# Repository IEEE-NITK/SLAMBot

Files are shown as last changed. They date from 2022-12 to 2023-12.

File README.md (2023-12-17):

# SLAMBot

## Achievements

- <span style="font-size: 1.2em;">**Winner of the IEEE R10 Undergraduate Project Video Competition 2023**</span>
  - <span style="font-size: 1.2em;">Category: AI and Robotics</span>
  - <span style="font-size: 1.2em;">[View Announcement](https://sac.ieeer10.org/ug-student-project-video-contest/)</span>
- <span style="font-size: 1.2em;">**Featured on IEEE R10 SAC LinkedIn page**</span>
  - <span style="font-size: 1.2em;">[Check out the post](https://www.linkedin.com/feed/update/urn:li:activity:7112096967022845952/)</span>
- <span style="font-size: 1.2em;">**IEEE R10 Undergraduate Student Project Video Contest Submission**</span>
  - <span style="font-size: 1.2em;">[Watch the Video](https://www.youtube.com/watch?v=xg2uQ87B_d8)</span>







<br>
<details>
  <summary>Table of Contents</summary>
    <ol>
        <li>
            <a href="#introduction">Introduction</a>
            <ul>
                <li><a href="#technologies-used">Technologies Used</a></li>
            </ul>
        </li>
        <li>
            <a href="#literature-survey">Literature Survey</a>
            <ul>
                <li><a href="#robot-operating-system-ros">Robot Operating System (ROS)</a></li>
                <li><a href="#basic-terminologies-in-ros">Basic Terminologies in ROS</a></li>
                <li><a href="#turtlebot">Turtlebot</a></li>
                <li><a href="#lidar">LIDAR</a></li>
                <li><a href="#raspberry-pi">Raspberry Pi</a></li>
                <li><a href="#arduino-mega">Arduino Mega</a></li>
            </ul>
        </li>
        <li>
            <a href="#getting-started">Getting Started</a>
            <ul>
            <li><a href="#prerequisites">Prerequisites</a></li>
            <li><a href="#installation">Installation</a></li>
            </ul>
        </li>
        <li>
            <a href="#user-guide">User Guide</a>
                <ul>
                    <li><a href="#launching-gazebo-simulation">Launching Gazebo Simulation</a></li>
                    <li><a href="#slam-creating-a-map">SLAM: Creating a Map</a></li>
                    <li><a href="#saving-the-map">Saving the Map</a></li>
                    <li><a href="#slam-autonomous-navigation">SLAM: Autonomous Navigation</a></li>
                </ul>    
        </li>
        <li>
            <a href="#the-robot">The Robot</a> 
        </li>
        <li>
            <a href="#references">References</a> 
        </li>
        <li>
            <a href="#project-mentors">Project Mentors</a></li>
        </li>
        <li>
            <a href="#project-members">Project Members</a></li>
        </li> 
        <li>
            <a href="#license">License</a></li>
        </li>    
    </ol>
</details>

<hr>

## Introduction

<b>SLAM</b> (<b>S</b>imultaneous <b>L</b>ocalization <b>A</b>nd <b>M</b>apping) is an essential technology used in robotics that helps robots to estimate their position and orientation on a map while creating a map of the environment to carry out autonomous activities. 

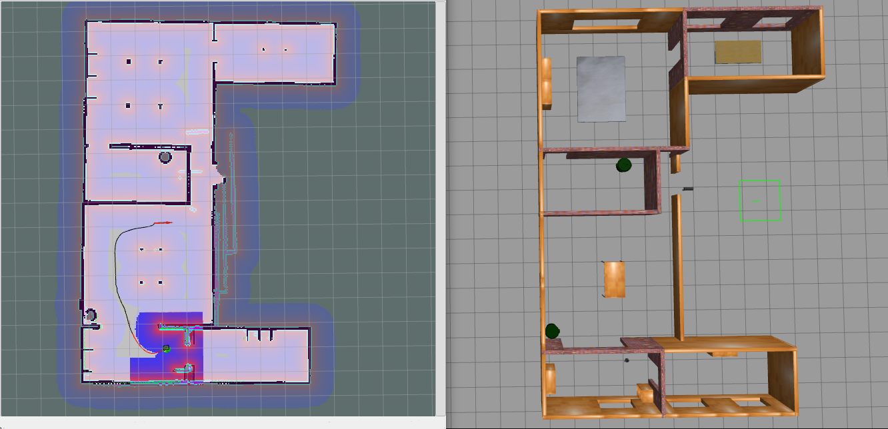
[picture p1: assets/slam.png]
SLAM

*Turtlebot using SLAM to navigate across a map*

This project aims to put together a mobile robot similar to a TurtleBot. A TurtleBot is a low-cost personal robot kit with open-source software.

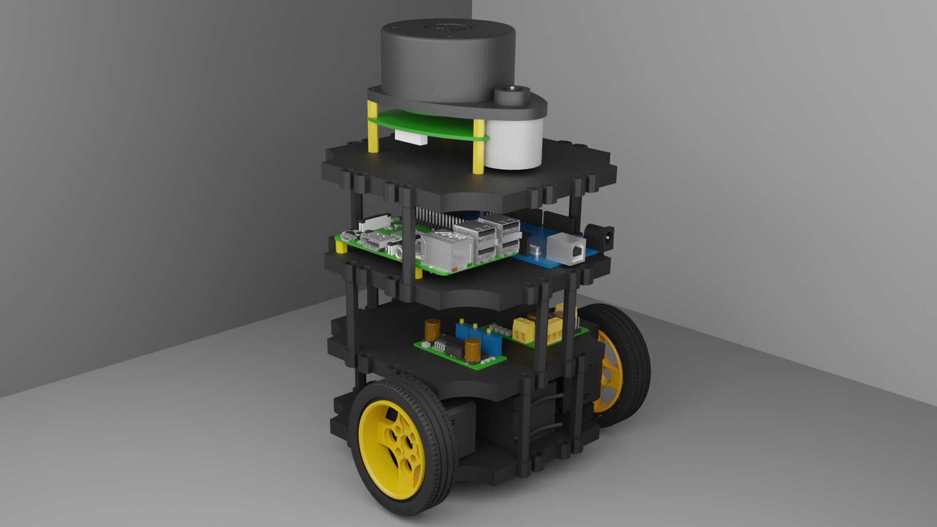
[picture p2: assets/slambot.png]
SlamBot

*SLAMBot Rendition*

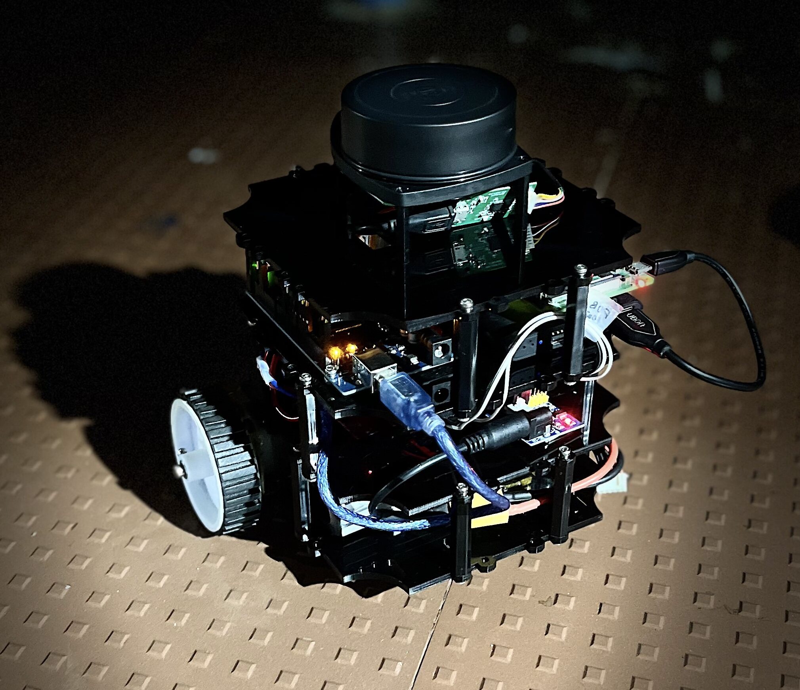
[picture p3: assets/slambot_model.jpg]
SlamBot Model

*Working model of SLAMBot*

### Technologies Used
Tech_Used (https://skills.thijs.gg)

## Literature Survey

### Robot Operating System (ROS)

ROS is an open-source, meta-operating system to operate robots. ROS provides the services of an operating system, such as hardware abstraction, low-level device control, implementation of commonly-used functionality, message-passing between processes, and package management. ROS provides tools and libraries for obtaining, building, writing, and running code across multiple computers. ROS currently only runs on Unix-based platforms. Software for ROS is primarily tested on Ubuntu and Mac OS X systems, though the ROS community has been contributing support for Fedora, Gentoo, Arch Linux, and other Linux platforms.

### Basic Terminologies in ROS:

* Nodes: A node is an executable that uses ROS to communicate with other nodes. A ROS Node can be a Publisher or a Subscriber. A Publisher puts the messages of a standard message type to a particular topic. The Subscriber, on the other hand, subscribes to the topic and receives the messages that are published to the topic.
* Messages: ROS data type used upon subscribing or publishing to a topic.
* Topics: Nodes can publish messages to a topic as well as subscribe to a topic to receive messages.
* Master: Name service for ROS (i.e. helps nodes find each other)
* rosout: ROS equivalent of stdout/stderr
* roscore: Master + rosout + parameter server (parameter server will be introduced later)

Client libraries needed for this project: 
* rospy: python client library 
* roscpp: c++ client library

### Turtlebot:

TurtleBot3 is a small, affordable, programmable, ROS-based mobile robot for education, research, hobby, and product prototyping. The TurtleBot’s core technology is SLAM, Navigation, and Manipulation, making it suitable for home service robots.
<p>
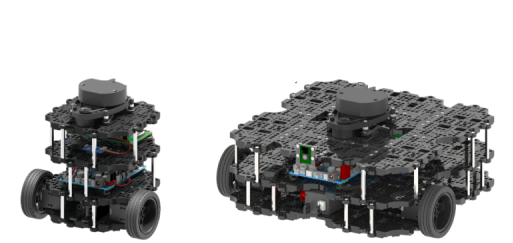
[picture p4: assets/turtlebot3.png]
Turtlebot
     
    <br>
    <em>Turtlebot3 Models - Burger and Waffle</em>
</p>

### LIDAR:

A <b>LIDAR</b> (<b>LI</b>ght <b>D</b>etection <b>A</b>nd <b>R</b>anging) is a sensor that uses light in the form of a pulsed laser to calculate the relative distances of various objects. This 3D scanning system calculates how long it takes for beams of light to hit an object or surface and reflect back to the laser scanner using the velocity of light. The observed LIDAR data is then used to generate precise, three dimensional information about the environment of the robot and navigate smoothly while avoiding the obstacles.

### Raspberry Pi:

The Raspberry Pi is an affordable single-board computer that can run Linux operating system such as Raspbian and Ubuntu. It is extensively used to develop programming skills or build hardware projects. It is a fast and versatile microprocessing board along with a set of GPIO (General Purpose Input/Output) pins, allowing one to control electronic components for physical computing. This project uses a Raspberry Pi 3B.

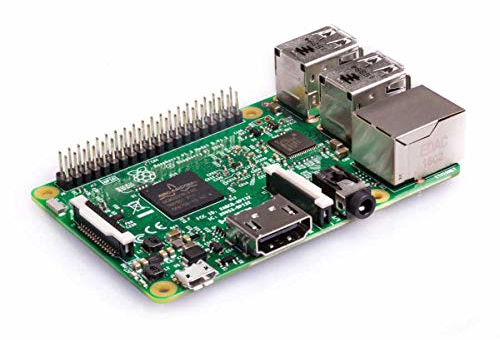
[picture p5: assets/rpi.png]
Raspi 3B
 
<br>
*Raspberry Pi Model B*

### Arduino Mega:

Arduino is an open-source electronics platform based on easy-to-use hardware and software intended for applications in interactive projects. Arduino Mega is a microcontroller development board based on the ATmega2560 microcontroller IC. It can be interfaced with various hardware components such as sensors and actuators. Arduino can be programmed using Arduino C which is a language based on C++.

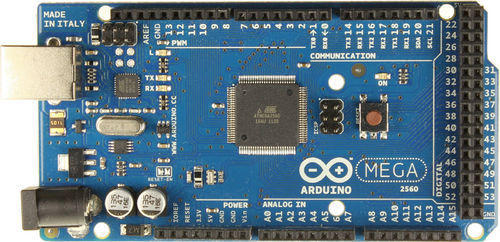
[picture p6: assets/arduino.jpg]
Arduino

<br>
*Arduino Mega*

## Getting Started

### Prerequisites

* Ubuntu 20.04
* ROS Noetic 

> For installing ROS refer to [ROS Wiki](http://wiki.ros.org/noetic/Installation)

### Installation

Create a catkin workspace

```bash
mkdir ros_ws
cd ros_ws
mkdir src
catkin build
```
To automatically source this workspace every time a new shell is launched, run these commands

```bash
echo "source ~/ros_ws/devel/setup.bash" >> ~/.bashrc
source ~/.bashrc
```

Clone the repository in the `src` folder in the catkin workspace.

```bash
cd ~/ros_ws/src
git clone https://github.com/IEEE-NITK/SLAMBot.git
```

Navigate back to the workspace folder and build the packages.

```bash
cd ~/ros_ws
catkin build
```

## User Guide

### Launching Gazebo Simulation

To launch the gazebo simulation use the command

```bash
roslaunch slambot_simulation slambot_simulation.launch
```

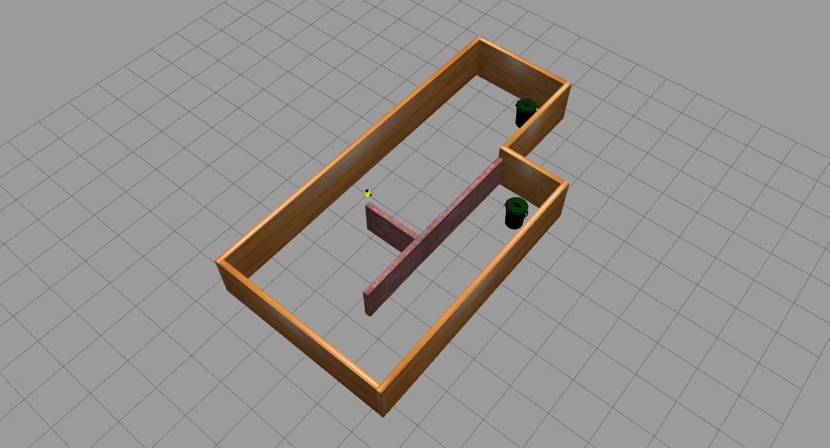
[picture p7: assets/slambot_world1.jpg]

<br>
*Slambot Simulation World*

To move the robot around, we will use teleop_twist_keyboard which is a package for moving the robot using the keyboard: 

```bash
rosrun teleop_twist_keyboard teleop_twist_keyboard.py 
```
### SLAM: Creating a Map

Before we can autonomously drive around any world, we need to provide the robot with a map which will be used to localize (position) the robot relative to obstacles or features defined in the map. We will create a new map of the default world by doing the following:

1. Launch the world in Gazebo
2. Launch the mapping script
3. Drive around and collect data from the robot's sensors until we have a (nearly) complete and accurate map.

After launching the gazebo simulation and teleoperation, use the following command to create a map using gmapping algorithm:

```bash
roslaunch slambot_simulation slambot_slam.launch
```

Now, with the terminal running the teleop_twist_keyboard selected, drive the robot around using the ```I```, ```J```, ```L```, ```,``` and ```K``` keys.

https://user-images.githubusercontent.com/97270737/211186864-b15c18e0-27f7-4a30-bb05-f40773bdc2ec.mp4

Once your map has all of the features defined (black for walls or obstacles, white for no obstacles, and gray/transparent for unknown regions), we need to save the map.

### Saving the Map

In a new terminal, run:

```bash
rosrun map_server map_saver -f ~/map
```

This will create two files:
* map.pgm - the image containing the white, gray, and black regions.
* map.yaml - the configuration data for the map.pgm image.

### SLAM: Autonomous Navigation

Now that the map of the world is prepared, we can drive the robot autonomously inside the world. To do this, we will:

1. Launch the gazebo simulation
2. Launch the naviation script
3. Set an initial pose estimate to align the map relative to the current sensor data (i.e. perform an initial localization)
4. Set target (goal) positions and orientations for the robot to drive to
5. Have the robot navigate to the goal autonomously

To launch the gazebo simuation, in a terminal run:

```bash
roslaunch slambot_simulation slambot_simulation.launch
```

Then in a new terminal, run

```bash
roslaunch slambot_simulation slambot_navigation.launch 
```
This will open an RViz window with the map and the robot with the current sensor values displayed.

In RViz

1. Select 2D Pose Estimate. Click and drag an arrow that estimates where the robot is currently positioned relative to the map that we created.
2. This will allign the robot to the map according to the current sensor feed.
3. Next, select 2D Nav Goal.
4. Click and drag an arrow that represents the position and orientation of where the robot needs to drive to. In order for a path to be calculated, this arrow must be inside a white or gray region, signifying that there is no known obstacle at the goal location.
5. The robot will compute a local path (a yellow arc) and a global path (the blue or red spline), and will autonomously drive to the target position.

https://user-images.githubusercontent.com/97270737/223050171-1a2402c0-27b5-4226-9031-b165af7b2f46.mp4

## The Robot

The robot model used in this project is a simple differential drive comprising of 2 wheels mounted on their motor along with a roller castor for additional base support.

The robot consists of 4 layers:

* Bottom-most layer: The propulsion group comprising of battery and motors.
* Second layer: It consists of the power distribution board along with motor drivers.
* Third layer: This layer has an Raspberry Pi, which is a single board computer, along with an Arduino Mega microcontroller.
* Top-most layer: It comprises of the LIDAR

The above mentioned plates are 3D printed parts which are further assembled with the electronic hardware using screws and supports to ensure stability of the structure.

The design of the bot is created on Fusion 360, a commercial CAD and CAM software. It is then directly exported as a URDF (Unified Robotic Description Format) file, accompanied by a .stl file of the model alongside a .launch and .yaml file to simulate it on Gazebo. The URDF is an XML file format for specifying the geometry and organization of robots in ROS and can be generated using URDF_Exporter. 

The robot is simulated in Gazebo, a powerful, open-source 3D robotics simulator with the ability to accurately and efficiently generate synthetic sensor data and offers realistic environments with high fidelity sensors streams to construct and interact with simulations. Within Gazebo, a physics engine is used to define realistic elements of an environment such as illumination, gravity and inertia.

## References

1. [ROS Wiki](http://wiki.ros.org/ROS/Tutorials)
2. [Turtlebot](https://www.turtlebot.com/about/)
3. [SLAM and Turtlebot](https://emanual.robotis.com/docs/en/platform/turtlebot3/slam/)

## Project Guide:
[Shobuj Paul](https://github.com/Shobuj-Paul)

## Project Mentors:

1. [Shivani Chanda](https://github.com/Shivani-Chanda)
2. [Spandan Patkar](https://github.com/SpandanPatkar)
3. [Sunaina Sunil](https://github.com/SunainaSunil)

## Project Members:

1. [Joel Jojo Painuthara](https://github.com/JoelJojoP)
2. [Pooja M](https://github.com/pooja-murugiah)
3. [Sakshi Bothra](https://github.com/Sakshi-1606)

## License:

This repository is licensed under the [BSD-3-Clause License](https://github.com/IEEE-NITK/SLAMBot/blob/main/LICENSE)

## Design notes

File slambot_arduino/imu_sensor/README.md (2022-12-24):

# Interfacing a MPU 9255 Sensor with Arduino Nano/Uno and ROS

Follow [this](https://github.com/Bill2462/MPU9255-Arduino-Library) GitHub repository to connect a MPU9255 IMU with a Arduino Board (Nano/Uno/Mega). Tested with Uno and Nano.

Follow the pin connections as given in the README. Import the library and use the given paramters as in the sample code.

Interface with ROS by declaring Publishers of message type **geometry_msgs/Vector3** to publish the IMU measurements to ROS after running `serial_node.py` (refer to main README).

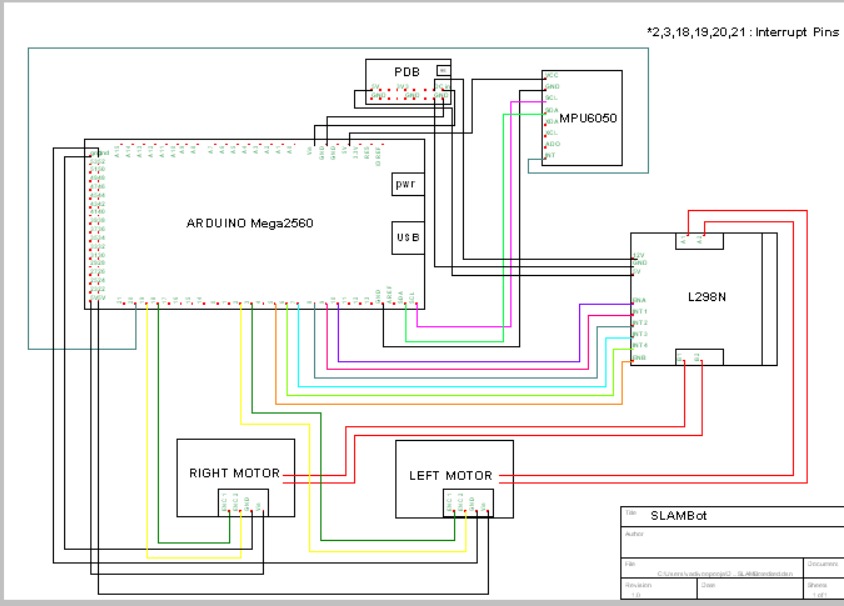
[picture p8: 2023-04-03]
pinout.jpeg

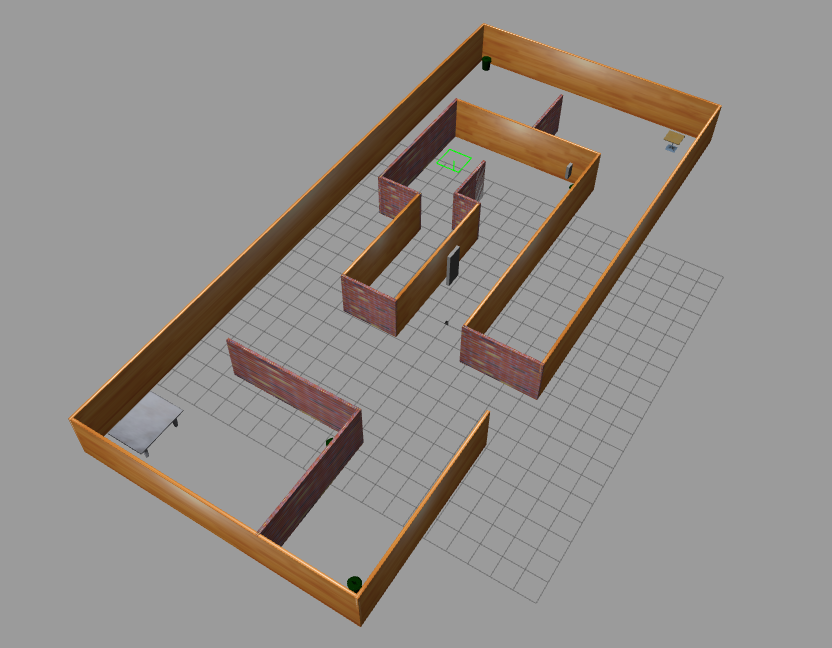
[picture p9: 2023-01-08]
assets/slambot_world.png

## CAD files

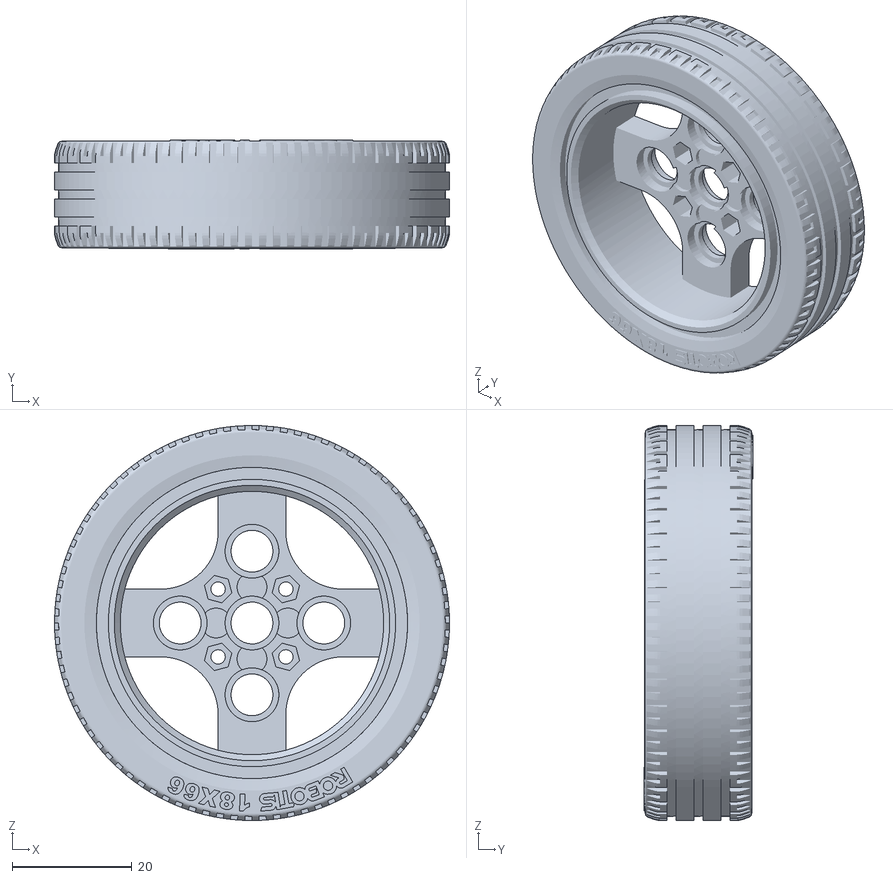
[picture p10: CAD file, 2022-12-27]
slambot_description/meshes/wheel_right_1.stl
66.0 x 18.2 x 66.0

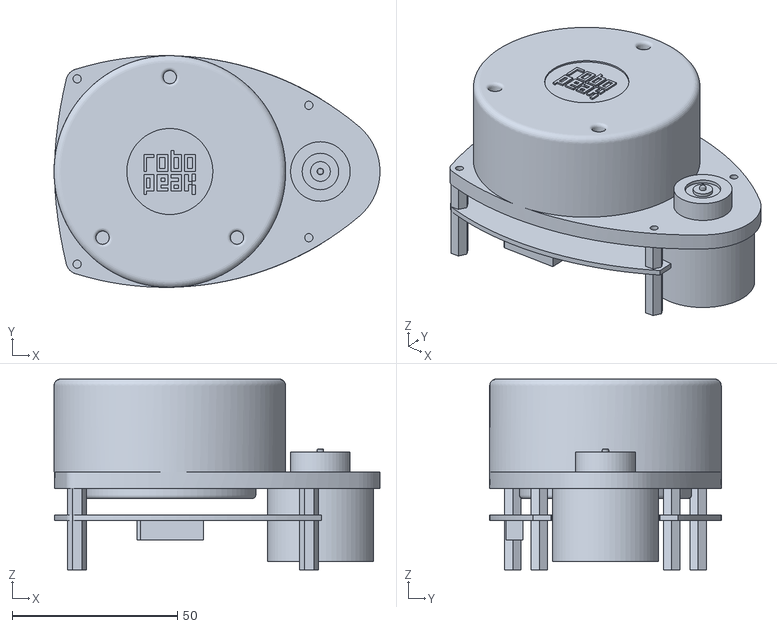
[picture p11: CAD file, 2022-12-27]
slambot_description/meshes/lidar_1.stl
98.5 x 70.0 x 57.7

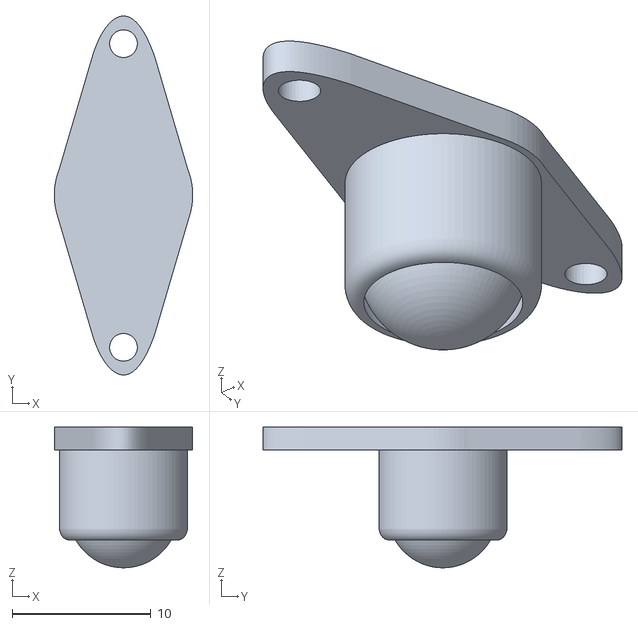
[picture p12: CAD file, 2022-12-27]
slambot_description/meshes/wheel_caster_1.stl
10.00 x 25.9 x 10.2

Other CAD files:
slambot_description/meshes/wheel_left_1.stl

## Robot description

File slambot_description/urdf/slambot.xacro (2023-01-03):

<?xml version="1.0" ?>
<robot name="slambot" xmlns:xacro="http://www.ros.org/wiki/xacro">

<xacro:include filename="$(find slambot_description)/urdf/materials.xacro" />
<xacro:include filename="$(find slambot_description)/urdf/slambot.trans" />
<xacro:include filename="$(find slambot_description)/gazebo/slambot_materials.gazebo" />
<xacro:include filename="$(find slambot_description)/gazebo/slambot_physics.gazebo" />
<xacro:include filename="$(find slambot_description)/gazebo/slambot_plugins.gazebo" />

<link name="base_footprint"/>
<link name="base_link">
  <inertial>
    <origin xyz="0.0028609830961275496 -0.00028636548319819235 0.07416570528182598" rpy="0 0 0"/>
    <mass value="5.29438449819002"/>
    <inertia ixx="0.018437" iyy="0.018264" izz="0.012718" ixy="4e-05" iyz="5.8e-05" ixz="0.000436"/>
  </inertial>
  <visual>
    <origin xyz="0 0 0" rpy="0 0 0"/>
    <geometry>
      <mesh filename="package://slambot_description/meshes/base_link.stl" scale="0.001 0.001 0.001"/>
    </geometry>
    <material name="opaque898684"/>
  </visual>
  <collision>
    <origin xyz="0 0 0" rpy="0 0 0"/>
    <geometry>
      <mesh filename="package://slambot_description/meshes/base_link.stl" scale="0.001 0.001 0.001"/>
    </geometry>
  </collision>
</link>

<link name="wheel_right_1">
  <inertial>
    <origin xyz="1.4796994004112607e-06 -0.00781748340988625 8.287650255650592e-08" rpy="0 0 0"/>
    <mass value="0.2346100571054497"/>
    <inertia ixx="9e-05" iyy="0.000167" izz="9e-05" ixy="0.0" iyz="-0.0" ixz="-0.0"/>
  </inertial>
  <visual>
    <origin xyz="-0.03275 0.0722 -0.033" rpy="0 0 0"/>
    <geometry>
      <mesh filename="package://slambot_description/meshes/wheel_right_1.stl" scale="0.001 0.001 0.001"/>
    </geometry>
    <material name="steel_satin"/>
  </visual>
  <collision>
    <origin xyz="-0.03275 0.0722 -0.033" rpy="0 0 0"/>
    <geometry>
      <mesh filename="package://slambot_description/meshes/wheel_right_1.stl" scale="0.001 0.001 0.001"/>
    </geometry>
  </collision>
</link>

<link name="wheel_left_1">
  <inertial>
    <origin xyz="1.4796994003002384e-06 0.007817483409885487 -8.287650261201707e-08" rpy="0 0 0"/>
    <mass value="0.2346100571054497"/>
    <inertia ixx="9e-05" iyy="0.000167" izz="9e-05" ixy="-0.0" iyz="-0.0" ixz="0.0"/>
  </inertial>
  <visual>
    <origin xyz="-0.03275 -0.0722 -0.0333" rpy="0 0 0"/>
    <geometry>
      <mesh filename="package://slambot_description/meshes/wheel_left_1.stl" scale="0.001 0.001 0.001"/>
    </geometry>
    <material name="steel_satin"/>
  </visual>
  <collision>
    <origin xyz="-0.03275 -0.0722 -0.0333" rpy="0 0 0"/>
    <geometry>
      <mesh filename="package://slambot_description/meshes/wheel_left_1.stl" scale="0.001 0.001 0.001"/>
    </geometry>
  </collision>
</link>

<link name="wheel_caster_1">
  <inertial>
    <origin xyz="-0.045000594596254544 1.735967801928781e-05 -0.00355326377799727" rpy="0 0 0"/>
    <mass value="0.0054901244015141525"/>
    <inertia ixx="0.0" iyy="0.0" izz="0.0" ixy="-0.0" iyz="0.0" ixz="0.0"/>
  </inertial>
  <visual>
    <origin xyz="-0.0 0.0 -0.01105" rpy="0 0 0"/>
    <geometry>
      <mesh filename="package://slambot_description/meshes/wheel_caster_1.stl" scale="0.001 0.001 0.001"/>
    </geometry>
    <material name="steel_satin"/>
  </visual>
  <collision>
    <origin xyz="-0.0 0.0 -0.01105" rpy="0 0 0"/>
    <geometry>
      <mesh filename="package://slambot_description/meshes/wheel_caster_1.stl" scale="0.001 0.001 0.001"/>
    </geometry>
  </collision>
</link>

<link name="lidar_1">
  <inertial>
    <origin xyz="-0.008711210990347865 -9.19261111398959e-05 0.03526812773284044" rpy="0 0 0"/>
    <mass value="1.3392997077576572"/>
    <inertia ixx="0.000619" iyy="0.000967" izz="0.001105" ixy="-1e-06" iyz="-3e-06" ixz="0.000159"/>
  </inertial>
  <visual>
    <origin xyz="-0.0 -0.0 -0.15105" rpy="0 0 0"/>
    <geometry>
      <mesh filename="package://slambot_description/meshes/lidar_1.stl" scale="0.001 0.001 0.001"/>
    </geometry>
    <material name="coating_black_oxide"/>
  </visual>
  <collision>
    <origin xyz="-0.0 -0.0 -0.15105" rpy="0 0 0"/>
    <geometry>
      <mesh filename="package://slambot_description/meshes/lidar_1.stl" scale="0.001 0.001 0.001"/>
    </geometry>
  </collision>
</link>

<joint name="base_joint" type="fixed">
  <parent link="base_footprint"/>
  <child link="base_link"/>
</joint>

<joint name="motor_right" type="continuous">
  <origin xyz="0.03275 -0.0722 0.033" rpy="0 0 0"/>
  <parent link="base_link"/>
  <child link="wheel_right_1"/>
  <axis xyz="0.0 1.0 0.0"/>
</joint>

<joint name="motor_left" type="continuous">
  <origin xyz="0.03275 0.0722 0.0333" rpy="0 0 0"/>
  <parent link="base_link"/>
  <child link="wheel_left_1"/>
  <axis xyz="-0.0 1.0 -0.0"/>
</joint>

<joint name="caster_joint" type="fixed">
  <origin xyz="0.0 0.0 0.01105" rpy="0 0 0"/>
  <parent link="base_link"/>
  <child link="wheel_caster_1"/>
</joint>

<joint name="lidar_joint" type="fixed">
  <origin xyz="0.0 0.0 0.15105" rpy="0 0 0"/>
  <parent link="base_link"/>
  <child link="lidar_1"/>
</joint>

</robot>

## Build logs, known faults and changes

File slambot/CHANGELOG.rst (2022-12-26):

^^^^^^^^^^^^^^^^^^^^^^^^^^^^^^^^
Changelog for package slambot
^^^^^^^^^^^^^^^^^^^^^^^^^^^^^^^^

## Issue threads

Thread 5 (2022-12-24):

Arduino code and hardware interface to ROS

Shobuj-Paul, 2022-12-24:
Embedded code must be written to interface with Arduino Mega and the other sensors, such as encoders and IMU. This embedded code is written with the rosserial_arduino package library for easy serial interface with the companion computer.
All _.ino_ codes are maintained in [this](https://github.com/IEEE-NITK/SLAMBot/tree/main/slambot_arduino) folder and template code for rosserial is added [here](https://github.com/IEEE-NITK/SLAMBot/blob/main/slambot_arduino/differential_drive/differential_drive.ino).

Closed 2022-12-27.

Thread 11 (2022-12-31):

Differential Drive Plugin

Shobuj-Paul, 2022-12-31:
## Use case

To control the robot in Gazebo using keyboard bindings, we need to set up `/cmd_vel` topic which connects to the wheel controllers using a differential drive setup.

## Proposal

Use the [differential drive plugin](https://classic.gazebosim.org/tutorials?tut=ros_gzplugins#DifferentialDrive) as given in Gazebo documentation and edit the given parameters in the _slambot_plugins.gazebo_ file given [here](https://github.com/IEEE-NITK/SLAMBot/blob/differential_drive_plugin/slambot_description/gazebo/slambot_plugins.gazebo). Get the robot's physical parameters from the CAD model in Fusion360.

Shivani-Chanda, 2023-01-03:
differential drive plugin updated with the correct physical parameters.

Closed 2023-01-03.

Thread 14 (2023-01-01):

Embedded code for rosserial communication

Shobuj-Paul, 2023-01-01:
## Description

The Arduino side rosserial codes do not connect to any hardware actions yet. Functions for calculating odometry, transform, etc. need to be completed and stored in their respective message types for proper publisher-subscriber relations.

## Steps to Reproduce

Open the [_differential_drive.ino_](https://github.com/IEEE-NITK/SLAMBot/blob/rosserial/slambot_arduino/differential_drive/differential_drive.ino) code in Arduino IDE. Upload it to your Arduino Mega board after setting the port and board parameters.
Run the rosserial node after running `roscore`:
```bash
rosrun rosserial_arduino serial_node.py
```
Running `rostopic list` gives you a bunch of topics on your Linux PC, but the contents of these topics are blank (check `rostopic echo`). Do the necessary calculations and complete the Arduino functions. Complete the `void loop()` part of the code.

### Expected Results

Sensor readings from Encoders, IMU, etc., should be published accurately on the computer. Motors should correctly respond to `/cmd_vel` command given on the computer.

### Actual results

Blank topics, no response from `/cmd_vel`.

<!-- ## Screenshots (optional)

      Consider also attaching screenshots and/or videos to better
      illustrate the issue.

      You can upload them directly on GitHub by dragging and dropping into this issue.
      Beware that video file size is limited to 10MB.
-->

## Configuration

### ROS Configuration

Which ROS Version are you using?

- [x] Noetic
- [ ] Melodic
- [ ] Foxy
- [ ] Humble
- [ ] Rolling

### Operating System

Which OS are you using?

- [ ] Windows
- [ ] MacOS
- [x] Ubuntu Linux (Mention Version) 20.04
- [ ] Other Linux (Mention Below)

Shobuj-Paul, 2023-02-10:
The Arduino code can be structured like the Atmega328P-based OpenCR board like [this](https://github.com/ROBOTIS-GIT/OpenCR/tree/master/arduino/opencr_arduino/opencr/libraries/turtlebot3/examples/turtlebot3_burger).

SpandanPatkar, 2023-03-15:
@Shobuj-Paul I have Updated the Arduino Codes, please have a look at it once.

Shobuj-Paul, 2023-03-15:
Has hardware testing been done? If yes, then you can open a pull request.

Shobuj-Paul, 2023-03-17:
@SpandanPatkar Open a PR after confirming hardware testing and mention exactly the hardware tests conducted in the PR.

Closed 2023-04-03.

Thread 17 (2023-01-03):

LIDAR Plugin

Shobuj-Paul, 2023-01-03:
## Use case

A plugin for LIDAR needs to be added for range sensing and mapping.

## Proposal

Add the appropriate Gazebo plugin from their [page](https://classic.gazebosim.org/tutorials?tut=ros_gzplugins) in the _slambot_plugins.gazebo_ file.
Enable visualization in Gazebo. Keep the range as 6m, as that will be the range of our RPLidar.

Shivani-Chanda, 2023-01-05:
LIDAR plugin added with max range 6m, visualization enabled.

Shobuj-Paul, 2023-01-05:
Only normal "ray" should be used instead of "gpu_ray" because, for some reason, "gpu_ray" doesn't seem to give either proper visualization or work with Rviz.
Have fixed the issue in https://github.com/IEEE-NITK/SLAMBot/commit/9ad8e5f83634bb7824211e6ea094e0d7829cf498.
Have also changed the minimum range to _0.10_ since the robot body was interfering with the laser.

Shobuj-Paul, 2023-01-05:
Pull request can be opened for _lidar-plugin_ branch.

Closed 2023-01-05.

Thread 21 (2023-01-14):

Launch error

Shivani-Chanda, 2023-01-14:
There is an error while launching simulation.launch saying spawn failed.

Shivani-Chanda, 2023-01-29:
added joint_state_publisher and robot_state publisher nodes. Error resolved.

Closed 2023-01-29.

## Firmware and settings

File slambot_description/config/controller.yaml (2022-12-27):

slambot_controller:
  # Publish all joint states -----------------------------------
  joint_state_controller:
    type: joint_state_controller/JointStateController
    publish_rate: 50

  # Position Controllers --------------------------------------
  motor_right_position_controller:
    type: effort_controllers/JointPositionController
    joint: motor_right
    pid: {p: 100.0, i: 0.01, d: 10.0}
  motor_left_position_controller:
    type: effort_controllers/JointPositionController
    joint: motor_left
    pid: {p: 100.0, i: 0.01, d: 10.0}

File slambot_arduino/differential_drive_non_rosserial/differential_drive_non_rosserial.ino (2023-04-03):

#include <Wire.h>
#include <MPU6050.h>
#include <ros.h>
#include <geometry_msgs/Twist.h>
#include <nav_msgs/Odometry.h>
#include <sensor_msgs/Imu.h>
#include <sensor_msgs/JointState.h>
#include <tf2_msgs/TFMessage.h>


//Declare global variables
ros::NodeHandle node;                   //initialise ros node 
geometry_msgs::TransformStamped t;

nav_msgs::Odometry odometry;
sensor_msgs::Imu imu_msg;
sensor_msgs::JointState joint_states;
tf2_msgs::TFMessage transform;
geometry_msgs::Twist cmd_vel;         
geometry_msgs::Vector3 acc, gyro;
ros::Publisher mpu_acc("imu/accelerometer", &acc);
ros::Publisher mpu_gyro("/imu/data", &imu_msg);


MPU6050 mpu;
//const int MPU = 0x68; // MPU6050 I2C address

float g = 9.81;//value of gravitation acceleration
float pi = 3.14159;//value of Pi

// define pins
//encoder
int ENC1A = 2;
int ENC1B = 3;  // Encoder pins for right motor
int ENC2A  = 18;
int ENC2B = 19; // Encoder pins for left motor

//L298N Motor Driver
int ENA = 5 ; //motor driver PWM pins for Left motor
int ENB = 10; //motor driver PWM pins for Right motor
int INT_1 = 6; //direction control for left motor
int INT_2 = 7; //direction control for left motor
int INT_3 = 8; //direction control for right motor
int INT_4 = 9; //direction control for right motor

//Acceleration and Rotation rate values
int16_t ax, ay, az;
int16_t gx, gy, gz;

//Timer for mpu values
float timeStep = 0.01;
unsigned long timer = 0;

//Encoder count values
int pulses_left = 0;
int pulses_right = 0;

//Variables to determine each cycle to get robot odometry position
double pos_left = 0;
double pos_right = 0;
double pos_left_mm =0;
double pos_right_mm = 0;
double pos_old_left_mm = 0;
double pos_old_right_mm = 0;
double pos_left_diff = 0;
double pos_right_diff = 0;
double pos_average_diff = 0;
double pos_total = 0;

// tf variables to broadcast
double y=0;                                   // position in y direction
double x=0;                                   // position in x direction
double theta = 0;                             //yaw angle in radians

//Robot Values
float wheel_base = 0.193;//please enter wheel dist. value
float radius = 0.065 ; // Radius of wheel = 65mm
float encoderppr = 400;

//Callback functions
float linear_x;
float linear_y;
float linear;
float angle;

//Motor Velocities
float vel_right;
float vel_left;


//Left motor encoder counter
void encoderLeftMotor() {
  if (digitalRead(ENC1A) == digitalRead(ENC1B)){
    pos_left++;
    pulses_left++;
  }
  else{
    pos_left--;
    pulses_left--;
  } 
}

//Right motor encoder counter
void encoderRightMotor() {
  if (digitalRead(ENC2A) == digitalRead(ENC2B)){
    pos_right--;
    pulses_right--;
  }
  else{
    pos_right++;
    pulses_right++;
  }
}

//Calculate motor velocities inside this
void velocity_callback(const geometry_msgs::Twist &vel_msg)
{
  // based on twist.subscriber
  linear_x = cmd_vel.linear.x;
  linear_y = cmd_vel.linear.y;
  angle = cmd_vel.angular.z;

  linear =sqrt(sq(linear_x) + sq(linear_y)); 

  vel_right = (angle * wheel_base) / 2 + linear;   //right motor velocity
  vel_left = linear * 2 - vel_right;               //left motor velocity
  
 
}


//Calculate transform for base_footprint
void calculate_transform()
{
    theta += ((pos_left_diff-pos_right_diff)/wheel_base);
    //please complete the function
    t.transform.rotation.z = theta;
}

//Calculate odometry from encoder values
void calculate_odometry()
{
  // Determining position
    pos_left_mm = (pos_left/encoderppr) * 2*PI*radius;
    pos_right_mm = (pos_right/encoderppr) * 2*PI*radius;
    pos_left_diff = pos_left_mm - pos_old_left_mm;
    pos_right_diff = pos_right_mm - pos_old_right_mm;
    pos_old_left_mm = pos_left_mm;
    pos_old_right_mm = pos_right_mm;

    pos_average_diff = (pos_left_diff + pos_right_diff)/2;
    pos_total += pos_average_diff;

    theta += ((pos_left_diff-pos_right_diff)/wheel_base);    

    if (theta > PI)
    theta -= TWO_PI;
    if(theta < -(PI))
    theta += TWO_PI;

    y += pos_average_diff * sin(theta);
    x += pos_average_diff * cos(theta);

    odometry.pose.pose.position.x = x;
    odometry.pose.pose.position.y = y;
    odometry.pose.pose.position.z = 0.0;
}

//Calculate joint states from encoder values
sensor_msgs::JointState calculate_joint_states()
{
  /*string[] name, float64[] position, float64[] velocity, float64[] effort*/
  joint_states.name = 'revolute';
  *joint_states.position = theta;
  *joint_states.velocity = (vel_right + vel_left)/2;  
  //joint_states.effort=;
  return joint_states;
  
}

//Calculate acceleration from IMU values
/*sensor_msgs::Imu calculate_imu()
{
  mpu.CalibrateGyro();
  mpu.getMotion6(&ax, &ay, &az, &gx, &gy, &gz);
  
  //mpu.getAcceleration(&ax, &ay, &az);
  //mpu.getRotation(&gx, &gy, &gz);
  //mpu.read_acc();//get data from the accelerometer
  //mpu.read_gyro();//get data from the gyroscope\
  


  //converts accel values to m per sec^2
  acc.x = ((float)ax*g)/16384;
  acc.y = ((float)ay*g)/16384;
  acc.z = ((float)az*g)/16384;

  //convert of gyro values to rad/sec^2 
  gyro.x = ((float)gx*pi)/180;
  gyro.y = ((float)gy*pi)/180;
  gyro.z = ((float)gz*pi)/180;*

  imu_msg.publish(&acc);
  imu_msg.publish(&gyro);

  gyro.publish(imu_msg);
  return imu_msg;
}*/

//Initialise nodes, publishers, subscribers and serial monitor
void setup()
{
  Serial.begin(9600);                           //modified baudrate
  Serial.println("Starting...");
  
  //Initial Setup for Encoder
  pinMode(ENC1A,INPUT);
  pinMode(ENC1B,INPUT);
  pinMode(ENC2A,INPUT);
  pinMode(ENC2B,INPUT);
  attachInterrupt(digitalPinToInterrupt(ENC1A),encoderLeftMotor,RISING);
  attachInterrupt(digitalPinToInterrupt(ENC2A),encoderRightMotor,RISING);

  pinMode(ENA, OUTPUT);   //please change these
  pinMode(ENB, OUTPUT);  //please change these

  //Initial Setup for MPU6050 I2C in Arduino C
  /*
  //Initial Setup for MPU6050 I2C in AVRC
  Wire.begin();                      // Initialize comunication
  Wire.beginTransmission(MPU);       // Start communication with MPU6050 // MPU=0x68
  Wire.write(0x6B);                  // Talk to the register 6B
  Wire.write(0x00);                  // Make reset - place a 0 into the 6B register
  Wire.endTransmission(true);        //end the transmission
  
  // Configure Accelerometer Sensitivity - Full Scale Range (default +/- 2g)
  Wire.beginTransmission(MPU);
  Wire.write(0x1C);                  //Talk to the ACCEL_CONFIG register (1C hex)
  Wire.write(0x10);                  //Set the register bits as 00010000 (+/- 8g full scale range)
  Wire.endTransmission(true);
  // Configure Gyro Sensitivity - Full Scale Range (default +/- 250deg/s)
  Wire.beginTransmission(MPU);
  Wire.write(0x1B);                   // Talk to the GYRO_CONFIG register (1B hex)
  Wire.write(0x10);                   // Set the register bits as 00010000 (1000deg/s full scale)
  Wire.endTransmission(true);
  delay(20);
  
  // Call this function if you need to get the IMU error values for your module
  calculate_IMU_error();
  delay(20);
  */

  //ROS Publishers and subscribers
  /*node.initNode();
  node.advertise(odometry_publisher);
  node.advertise(imu_publisher);
  node.advertise(transform_publisher);
  node.advertise(joint_state_publisher);
  node.subscribe(twist_subscriber);
  */
}

//Write your program logic
void loop()
{
  //Controlling speed (0 = off and 255 = max speed):
  /*Caution: The motors are 300 rpm please don't use PWM values greater than 75*/
  analogWrite(ENA, 0); //ENA pin //RIGHT
  analogWrite(ENB, 0); //ENB pin

  //Controlling spin direction of motors:
  //digitalWrite(INT_4, HIGH);
  //digitalWrite(INT_3, LOW);

  digitalWrite(INT_2, HIGH);
  digitalWrite(INT_1, LOW);
  

  Serial.println("Encoder Count");
  Serial.println(pulses_right);
  Serial.println(pulses_left);
  Serial.println(".........................");

  
  /*
  Serial.println("Encoder Count");
  Serial.println(pulses_right);
  Serial.println(pulses_left);
  Serial.println(".........................");
  */
  node.spinOnce();

  //delay(2000);
}

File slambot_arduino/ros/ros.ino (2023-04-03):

#include <ros.h>
#include <std_msgs/String.h>
#include <tf/tf.h>
#include <tf/transform_broadcaster.h>
#include <nav_msgs/Odometry.h>
#include <geometry_msgs/Twist.h>
#include <ros/time.h>


//initializing all the variables
//timers for sub-main loop
#define LOOPTIME 100                //Looptime in millisecond
const byte noCommLoopMax = 10;                //number of main loops the robot will execute without communication before stopping
unsigned int noCommLoops = 0;                 //main loop without communication counter
unsigned long lastMilli = 0;


const int PIN_ENCOD_A_MOTOR_LEFT = 3;             //A channel for encoder of left motor 
const int PIN_ENCOD_A_MOTOR_RIGHT = 2;              //A channel for encoder of right motor   
const byte M[4] = {5, 6, 7, 8};

//Variables to determine each cycle to get robot odometry position
double pos_left_mm =0;
double pos_right_mm = 0;
double pos_old_left_mm = 0;
double pos_old_right_mm = 0;
double pos_left_diff = 0;
double pos_right_diff = 0;
double pos_average_diff = 0;
double pos_total = 0;

// tf variables to broadcast
double y=0;                                   // position in y direction
double x=0;                                   // position in x direction
double theta = 0;                             //yaw angle in radians

//function that will be called when receiving command from host
void handle_cmd (const geometry_msgs::Twist& cmd_vel) {
noCommLoops = 0;  
x_pos_req=msg.linear.x
y_pos_req=msg.linear.y
theta_req=msg.angular.z
}

ros::NodeHandle nh;     //initialise ros node nh
char odom[] = "/odom";
char base_link[] = "/base_link";
ros::Subscriber<geometry_msgs::Twist> cmd_vel("cmd_vel", handle_cmd);   //create a subscriber to ROS topic for velocity commands (will execute "handle_cmd" function when receiving data)
nav_msgs::Odometry odom_msg;                                            //create an "odom_msg" ROS message
ros::Publisher odom_pub("odometry", &odom_msg);                         //create a publisher to ROS topic "odometry" using the "odom_msg" type
tf::TransformBroadcaster broadcaster; 


void setup() {
  nh.getHardware()->setBaud(500000);         //set baud for ROS serial communication
  nh.initNode();                            //init ROS node
  nh.subscribe(cmd_vel);                    //suscribe to ROS topic for velocity commands
  nh.advertise(odom_pub);                  //prepare to publish speed in ROS topic
  broadcaster.init(nh);



  // Define the rotary encoder for left motor
  pinMode(PIN_ENCOD_A_MOTOR_LEFT, INPUT); 
  pinMode(PIN_ENCOD_B_MOTOR_LEFT, INPUT); 
  digitalWrite(PIN_ENCOD_A_MOTOR_LEFT, HIGH);                // turn on pullup resistor
  digitalWrite(PIN_ENCOD_B_MOTOR_LEFT, HIGH);
  attachInterrupt(digitalPinToInterrupt(PIN_ENCOD_A_MOTOR_LEFT), encoderLeftMotor, RISING);

  // Define the rotary encoder for right motor
  pinMode(PIN_ENCOD_A_MOTOR_RIGHT, INPUT); 
  pinMode(PIN_ENCOD_B_MOTOR_RIGHT, INPUT); 
  digitalWrite(PIN_ENCOD_A_MOTOR_RIGHT, HIGH);                // turn on pullup resistor
  digitalWrite(PIN_ENCOD_B_MOTOR_RIGHT, HIGH);
  attachInterrupt(digitalPinToInterrupt(PIN_ENCOD_A_MOTOR_RIGHT), encoderRightMotor, RISING);
}

void loop() {
  nh.spinOnce();
  if((millis()-lastMilli) >= LOOPTIME){                                                                           // enter timed loop
    lastMilli = millis();
    
    if (abs(pulses_left) < 5){                                                   //Avoid taking in account small disturbances
      speed_act_left = 0;
    }
    else {
      speed_act_left=((pulses_left/encoderppr)*2*PI)*(1000/LOOPTIME)*radius;           // calculate left wheel speed in m/s
      pulses_left = 0;                                                                 // reset pulses to 0 for next loop
    }
    
    if (abs(pulses_right) < 5){                                                         //Avoid taking in account small disturbances
      speed_act_right = 0;
    }
    else {
    speed_act_right=((pulses_right/encoderppr)*2*PI)*(1000/LOOPTIME)*radius;           // calculate right wheel speed in m/s
    pulses_right=0;
    }





    if (noCommLoops >= noCommLoopMax) {                   //Stopping if too much time without command
      speed_req_left=0;
      }

    if((millis()-lastMilli) >= LOOPTIME){         //write an error if execution time of the loop in longer than the specified looptime
      //Serial.println(" TOO LONG ");
    }

    noCommLoops++;
    if (noCommLoops == 65535){
      noCommLoops = noCommLoopMax;
    }


// Determining position
    pos_left_mm = (pos_left/encoderppr) * 2*PI*radius;
    pos_right_mm = (pos_right/encoderppr) * 2 * PI * radius;
    pos_left_diff = pos_left_mm - pos_old_left_mm;
    pos_right_diff = pos_right_mm - pos_old_right_mm;
    pos_old_left_mm = pos_left_mm;
    pos_old_right_mm = pos_right_mm;

    pos_average_diff = (pos_left_diff + pos_right_diff)/2;
    pos_total += pos_average_diff;

    if (speed_handle_left == speed_handle_right);
    else
    theta += ((pos_left_diff-pos_right_diff)/wheeltrack);    

    if (theta > PI)
    theta -= TWO_PI;
    if(theta < -(PI))
    theta += TWO_PI;

    y += pos_average_diff * sin(theta);
    x += pos_average_diff * cos(theta);

   publishOdometry(LOOPTIME);   //Publish odometry on ROS topic
 }
}

void publishOdometry(double time) {
  geometry_msgs::TransformStamped t;
  t.header.frame_id = odom;
  t.child_frame_id = base_link;
  t.transform.translation.x = x;       //robot position in X direction in mm
  t.transform.translation.y = y;       // robot position in Y direction in mm
  t.transform.translation.z = 0;
  t.transform.rotation = tf::createQuaternionFromYaw(theta);
  t.header.stamp = nh.now();
  broadcaster.sendTransform(t);

  nav_msgs::Odometry odom_msg;
  odom_msg.header.stamp = nh.now();      //timestamp for odometry data
  odom_msg.pose.pose.position.x = x;
  odom_msg.pose.pose.position.y = y;
  odom_msg.pose.pose.orientation = tf::createQuaternionFromYaw(theta);
  odom_msg.twist.twist.linear.x = speed_act_left;    //left wheel speed (in m/s)
  odom_msg.twist.twist.linear.y = speed_act_right;   //right wheel speed (in m/s)
  odom_msg.twist.twist.angular.z = time/1000;         //looptime, should be the same as specified in LOOPTIME (in s)
  odom_pub.publish(&odom_msg);
  nh.spinOnce();
  nh.loginfo("Publishing odometry");
}





//Left motor encoder counter
void encoderLeftMotor() {
  if (digitalRead(PIN_ENCOD_A_MOTOR_LEFT) == digitalRead(PIN_ENCOD_B_MOTOR_LEFT)){
    pos_left++;
    pulses_left++;
  }
  else{
    pos_left--;
    pulses_left--;
  } 
}
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

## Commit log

2022-12-04 arduino code folder for uploading to the embedded board and interface with RPi using serial comms
2022-12-21 added template code for interfacing a lone IMU sensor
2022-12-25 made few corrections in topics
    [differential_drive.ino]
2022-12-25 added motor control code for motor driver
2022-12-26 URDF description added
    [Caster_Ball_Wheel_Small_v7_1.stl, RPLidar_v1_1.stl, Wheel_1_v1_1.stl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]
2022-12-26 slambot_description directory deleted
    [Caster_Ball_Wheel_Small_v7_1.stl, RPLidar_v1_1.stl, Wheel_1_v1_1.stl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]
2022-12-26 URDF description revised and added
    [controller.yaml, lidar_1.stl, materials.xacro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]
2022-12-27 slambot_description deleted
    [controller.yaml, lidar_1.stl, materials.xacro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]
2022-12-31 restructured slambot_desciption package
    [controller.yaml, slambot.xacro]
2023-01-03 added a base_footprint would prove useful when setting up navigation
    [slambot.xacro]
2023-01-05 lidar plugin added
2023-01-05 fixed gpu_ray, only normal laser should be used
2023-01-08 fixed differential drive code
    [differential_drive.ino]
2023-01-08 Initial Documentation (#20)
    * Added Introduction
    * Resources for README
    * Updated Introduction
    * Minor Correction
    * Update README.md
    * Update README.md
    * Update README.md
    * Update README.md
    * Update README.md
    * Update README.md
    * Update README.md
    * Update README.md
    * Update README.md
    * Update README.md
    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
2023-01-29 added joint state and robot state pulisher nodes . Bug resolved.
2023-02-07 arduino codes added
2023-02-19 Updated codes for encoder check
2023-03-06 Configure IMU function in Differential Drive
2023-03-29 wheel_base value Updated
2023-03-30 reference code for odometry
2023-03-30 Debugged Codes for Arduino 30/03
2023-04-01 Fixed MPU function, --to complete a.Callback b.Subs Declaration 01/04
    [differential_drive.ino]
2023-05-03 lidar configuration modified
